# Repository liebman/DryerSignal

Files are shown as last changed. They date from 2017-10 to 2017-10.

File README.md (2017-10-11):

# Simple Dryer Signal
I have a cheap dryer, it has no "done" signal.  I'm adding one using a current sensor and an ATTiny85

[DryerSignal](DryerSignal) contains the code for the ATTiny85.  I used [Eclipse with an Arduino plugin](http://sloeber.io) for development.  If you want to use the Arduino IDE then create an empty file named DryerSignal.ino

[eagle](eagle) contains the [Eagle](https://www.autodesk.com/products/eagle/overview) design files.

Its a work in progress....

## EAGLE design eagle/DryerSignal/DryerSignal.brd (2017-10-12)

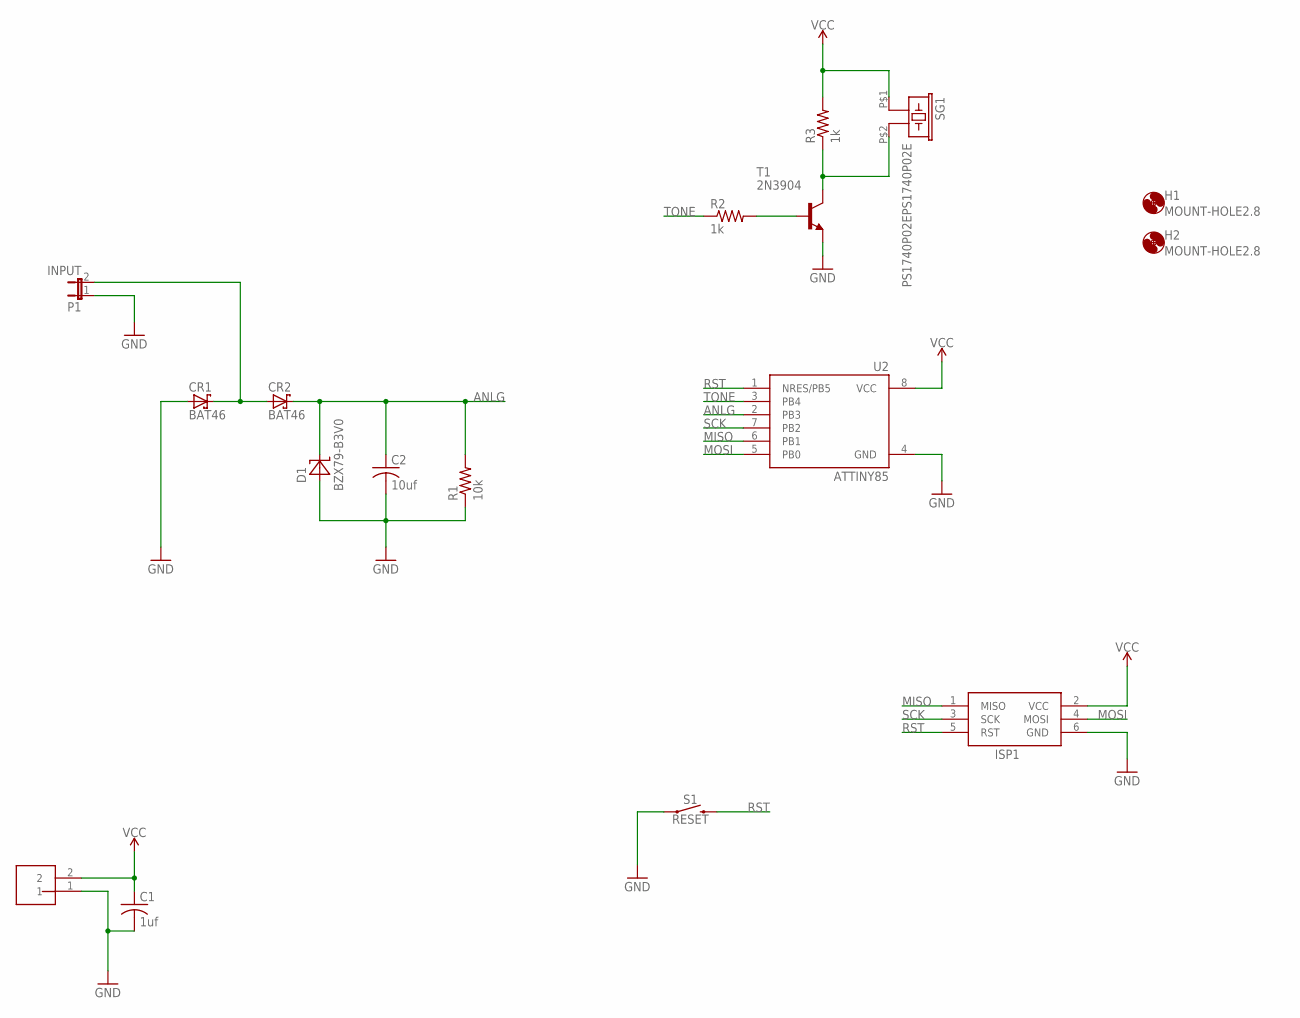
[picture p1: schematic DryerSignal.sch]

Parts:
C1: 1uf; C050-025X075
C2: 10uf; C050-025X075
CR1, CR2: BAT46; DO35-10
D1: BZX79-B3V0; DO35-10
H1, H2: MOUNT-HOLE2.8; 2,8
ISP1: AVRISP-BOX
J1: 4.5v; 2_PIN_JST-XH
P1: INPUT; 1X02
R1: 10k; 0207/10
R2, R3: 1k; 0207/10
S1: RESET; 1X02
SG1: PS1740P02EPS1740P02E; PS1740P02E
T1: 2N3904; TO92
U2: ATTINY85; PDIP08_300MIL

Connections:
ANLG: C2.1, CR2.C, D1.C, R1.2, U2.2 (PB3)
GND: C1.2, C2.2, CR1.A, D1.A, ISP1.6 (GND), J1.1, P1.1, R1.1, S1.1, T1.3 (E), U2.4 (GND)
INPUT: CR1.C, CR2.A, P1.2
MISO: ISP1.1 (MISO), U2.6 (PB1)
MOSI: ISP1.4 (MOSI), U2.5 (PB0)
unnamed: R2.2, T1.2 (B)
unnamed: R3.1, SG1.P$2 (2), T1.1 (C)
RST: ISP1.5 (RST), S1.2, U2.1 (NRES/PB5)
SCK: ISP1.3 (SCK), U2.7 (PB2)
TONE: R2.1, U2.3 (PB4)
VCC: C1.1, ISP1.2 (VCC), J1.2, R3.2, SG1.P$1 (1), U2.8 (VCC)

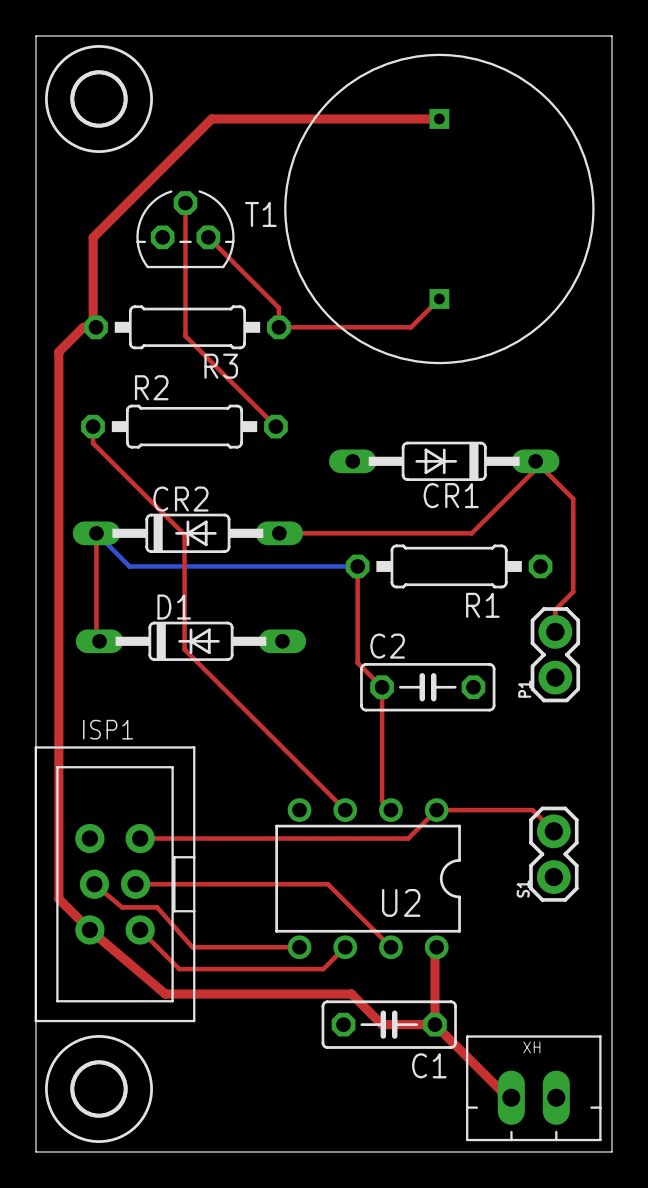
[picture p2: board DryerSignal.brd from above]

Board: 2 copper layers, 32.0 x 62.0 mm, 17 parts (0 on the bottom side), 11 nets.

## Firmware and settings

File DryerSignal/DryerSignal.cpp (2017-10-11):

//
// I use a nano for debugging...
//
#if defined(ARDUINO_AVR_NANO)
#define DEBUG
#endif

#include "DryerSignal.h"

void (*timer_cb)();
volatile bool timer_running;
volatile unsigned int start_time;
volatile unsigned int pwm_duration;     // PWM cycle count down.
volatile unsigned int state_count;
unsigned int saved_count;

int state;

ISR(WDT_vect)
{
#if defined(LED_PIN)
    digitalWrite(LED_PIN, !digitalRead(LED_PIN));
#endif

    state_count += 1; // time in current state

    // ReEnable the watchdog interrupt, as this gets reset when entering this ISR and
    // automatically enables the WDE signal that resets the MCU the next time the
    // timer overflows
#if defined(__AVR_ATtinyX5__)
    WDTCR |= bit (WDIE);
#else
    WDTCSR |= bit (WDIE);
#endif
}

void clearTimer()
{
#if defined(__AVR_ATtinyX5__)
    TCCR1 = 0;
    GTCCR = 0;
    TIMSK &= ~(_BV(TOIE1) | _BV(OCIE1A) | _BV(OCIE1A));
#else
    TCCR1A = 0;
    TCCR1B = 0;
    TIMSK1 = 0;
#endif
    OCR1A  = 0;
    OCR1B  = 0;
}

ISR(TIMER1_OVF_vect)
{
    if (pwm_duration == 0)
    {
        return;
    }

    pwm_duration -= 1;
    if (pwm_duration == 0)
    {
        clearTimer();
        timer_running = false;
        if (timer_cb != NULL)
        {
            timer_cb();
        }
    }
}

ISR(TIMER1_COMPA_vect)
{
    unsigned int int_time = millis();

    // why to we get an immediate interrupt? (ignore it)
    if (int_time == start_time || int_time == start_time+1)
    {
        return;
    }

#if defined(__AVR_ATtinyX5__)
    TIMSK &= ~(1 << OCIE1A); // disable timer1 interrupts as we only want this one.
#else
    TIMSK1 &= ~(1 << OCIE1A); // disable timer1 interrupts as we only want this one.
#endif
    timer_running = false;
    if (timer_cb != NULL)
    {
        timer_cb();
    }
}

void startTimer(unsigned int ms, void (*func)())
{
    start_time = millis();
    uint16_t timer = ms2Timer(ms);
    // initialize timer1
    noInterrupts();
    // disable all interrupts
    timer_cb = func;
#if defined(__AVR_ATtinyX5__)
    TCCR1 = 0;
    TCNT1 = 0;

    OCR1A = timer;   // compare match register
    TCCR1 |= (1 << CTC1);// CTC mode
    TCCR1 |= PRESCALE_BITS;
    TIMSK |= (1 << OCIE1A);// enable timer compare interrupt
    // clear any already pending interrupt?  does not work :-(
    TIFR &= ~(1 << OCIE1A);
#else
    TCCR1A = 0;
    TCCR1B = 0;
    TCNT1 = 0;

    OCR1A = timer;   // compare match register
    TCCR1B |= (1 << WGM12);   // CTC mode
    TCCR1B |= PRESCALE_BITS;
    TIMSK1 |= (1 << OCIE1A);  // enable timer compare interrupt
    // clear any already pending interrupt?  does not work :-(
    TIFR1 &= ~(1 << OCIE1A);
#endif
    timer_running = true;
    interrupts();
    // enable all interrupts
}

void startPWM(unsigned int duration, unsigned int top, void (*func)())
{
    noInterrupts();
    timer_cb = func;

    clearTimer();

#if defined(__AVR_ATtinyX5__)
    OCR1C = top-1;
#else
    ICR1  = top-1;
#endif

    OCR1B = 50*top/100;
    TCNT1 = 0; // needed???
#if defined(__AVR_ATtinyX5__)
    TCCR1 = PWM_PRESCALE_BITS;
    GTCCR = _BV(COM1B1) | _BV(PWM1B);
#else
    TCCR1A =  _BV(COM1B1) | _BV(WGM10);
#endif

#if defined(__AVR_ATtinyX5__)
    TIMSK |= _BV(TOIE1);
#else
    TCCR1B = _BV(WGM12) | PWM_PRESCALE_BITS;
    TIMSK1 = _BV(TOIE1);
#endif

    pwm_duration = F_CPU / PWM_PRESCALE / top / (1000.0 / (double)duration);
    timer_running = true;
    interrupts();
}

void alertTone();

volatile bool         alert_active;
volatile unsigned int alert_top;
volatile unsigned int alert_duration;
volatile unsigned int alert_delay;
volatile          int alert_count;

void alertDelay()
{
    alert_count -= 1;
    if (alert_count < 1)
    {
        alert_count  = 0;
        alert_active = false;
        return;
    }

    startTimer(alert_delay, &alertTone);
}

void alertTone()
{
    startPWM(alert_duration, alert_top, &alertDelay);
}

void startAlert(unsigned int top, unsigned int duration, unsigned int delay, unsigned int count)
{
    dbprintf("startAlert top:%d duration:%d delay:%d count:%d\n", top, duration, delay, count);
    alert_active   = true;
    alert_top      = top;
    alert_duration = duration;
    alert_delay    = delay;
    alert_count    = count;
    alertTone();
}

void power_down()
{
    // disable ADC
    ADCSRA &= ~bit(ADEN);

    if (timer_running || alert_active)
    {
        set_sleep_mode(SLEEP_MODE_IDLE);
    }
    else
    {
        dbprintf("power_down using PWR_DOWN!\n");
        set_sleep_mode(SLEEP_MODE_PWR_DOWN);
    }

    dbflush();
    // sleep!
    sleep_enable();
    sleep_cpu();
    sleep_disable();
    // enable ADC
    ADCSRA |= bit(ADEN);
}

void setState(int new_state, unsigned int new_count)
{
    dbprintf("setState: %d count: %u\n", new_state, new_count);
    state       = new_state;
    state_count = new_count;
}

void setup()
{
    dbbegin(115200);
    dbprintln("Setup!");

#if defined(LED_PIN)
    digitalWrite(LED_PIN, HIGH);
    pinMode(LED_PIN, OUTPUT);
#endif

    digitalWrite(TONE_PIN, 0);
    pinMode(TONE_PIN, OUTPUT);

    setState(STATE_IDLE, 0);

    // clear various "reset" flags
    MCUSR = 0;
#if defined(__AVR_ATtinyX5__)
    // allow changes, disable reset
    WDTCR = bit (WDCE) | bit (WDE);
    // set interrupt mode and an interval
    WDTCR = bit (WDIE) | bit (WDP2) | bit (WDP1);    // set WDIE, and 1 second delay
#else
    // allow changes, disable reset
    WDTCSR = bit (WDCE) | bit (WDE);
    // set interrupt mode and an interval
    WDTCSR = bit (WDIE) | bit (WDP2) | bit (WDP1);    // set WDIE, and 1 second delay
#endif

    startAlert(START_TONE, START_DURATION, 25, 3);
}

int last_count;
void loop()
{
    power_down();

    //
    // don't run the logic if alert or timer running!
    //
    if (timer_running || alert_active)
    {
        if (last_count != alert_count)
        {
            dbprintf("alert_count: %d\n", alert_count);
            last_count = alert_count;
        }
        return;
    }

    int sample = analogRead(ANALOG_PIN);
    dbprintf("state: %d state_count: %d sample: %d\n", state, state_count, sample);

    switch(state)
    {
        case STATE_IDLE:
            if (sample >= SAMPLE_THRESHOLD)
            {
                setState(STATE_ARM, 0);
            }
            state_count = 0;
            break;
        case STATE_ARM:
            if (state_count >= COUNT_TO_ARMED)
            {
                setState(STATE_ARMED, 0);
            }
            else if (sample < SAMPLE_THRESHOLD)
            {
                saved_count = state_count;
                setState(STATE_DISARM, 0);
            }
            break;
        case STATE_DISARM:
            if (state_count >= MISS_TO_IDLE)
            {
                setState(STATE_IDLE, 0);
            }
            else if (sample >= SAMPLE_THRESHOLD)
            {
                setState(STATE_ARM, saved_count);
            }
            break;
        case STATE_ARMED:
            if (sample >= SAMPLE_THRESHOLD)
            {
                state_count = 0;
            }
            else if (state_count >= COUNT_TO_ALARM)
            {
                setState(STATE_ALARM, 0);
            }
            break;
        case STATE_ALARM:
            startAlert(ALARM_TONE, TONE_ON_MS, TONE_OFF_MS, ALARM_MAX_SECONDS);
            setState(STATE_IDLE, 0);
            break;
        default:
            dbprintf("unknown state: %d", state);
            state = STATE_IDLE;
    }
}

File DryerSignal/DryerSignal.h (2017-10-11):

#ifndef _DryerSignal_H_
#define _DryerSignal_H_

#include "Arduino.h"
#include <avr/sleep.h>
#include <avr/wdt.h>
#include "Logger.h"

#define USE_PWM
//#define TEST_SOUND

#define SAMPLE_THRESHOLD  5      // if we read higher than this its on!

#define COUNT_TO_ARMED    10     // 10 seconds with current will arm
#define MISS_TO_IDLE      2      // miss 2 seconds of zero current while arming goes back to idle
#define COUNT_TO_ALARM    10     // 10 seconds of no current for alarm if armed
#define ALARM_MAX_SECONDS 120    // 2 minutes max alarm tone

#define START_TONE        143    // ~3500hz
#define START_DURATION    100

#define ALARM_TONE        167    // ~3000hz
#define TONE_ON_MS        500
#define TONE_OFF_MS       500


#define STATE_IDLE        0
#define STATE_ARM         1
#define STATE_DISARM      2
#define STATE_ARMED       3
#define STATE_ALARM       4

#if defined(__AVR_ATtinyX5__)
#define ANALOG_PIN        A3
#define TONE_PIN          4
//#define LED_PIN           1
#elif defined(ARDUINO_AVR_NANO)
#define ANALOG_PIN        A1
#define TONE_PIN          3
#define LED_PIN           LED_BUILTIN
#endif

#if defined(__AVR_ATtinyX5__)
#if F_CPU == 1000000L
#define PWM_PRESCALE      2
#define PWM_TOP           125 // 4khz
#define PWM_PRESCALE_BITS (_BV(CS11))
#elif F_CPU == 8000000L
#define PWM_PRESCALE      8
#define PWM_TOP           250 // 4khz
#define PWM_PRESCALE_BITS (_BV(CS12))
#endif
#else
#define PWM_TOP           250 // assuming 16mhz CPU its 8khz
#define PWM_PRESCALE      8
#define PWM_PRESCALE_BITS (_BV(CS11))
#endif

#ifdef __AVR_ATtinyX5__
#if F_CPU == 8000000L
#define PRESCALE        4096
#define PRESCALE_BITS   ((1 << CS13) | (1 << CS12) | (1 <<CS10)) // 4096 prescaler
#elif F_CPU == 4000000L
#define PRESCALE        2048
#define PRESCALE_BITS   ((1 << CS13) | (1 << CS12)) // 2048 prescaler
#elif F_CPU == 1000000L
#define PRESCALE        4096
#define PRESCALE_BITS   ((1 << CS13) | (1 << CS12) | (1 <<CS10)) // 4096 prescaler
#endif
#define ms2Timer(x) ((uint8_t)(F_CPU /(PRESCALE * (1/((double)x/1000)))))
#else
#define PRESCALE        256
#define PRESCALE_BITS   (1 << CS12) // 256 prescaler
#define ms2Timer(x) ((uint16_t)(F_CPU /(PRESCALE * (1/((double)x/1000)))))
#endif

#endif /* _DryerSignal_H_ */

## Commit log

2017-10-11 initial import, still WIP
    [DryerSignal.brd, DryerSignal.sch]
2017-10-12 updated schematic & board to remove voltage regulator
    [DryerSignal.brd, DryerSignal.sch]

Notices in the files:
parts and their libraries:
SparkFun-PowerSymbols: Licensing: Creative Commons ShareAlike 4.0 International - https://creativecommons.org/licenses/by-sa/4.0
